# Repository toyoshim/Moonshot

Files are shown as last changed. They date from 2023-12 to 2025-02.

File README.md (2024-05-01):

# Moonshot
USB to Legacy Joystick port converter.

# License
The 3-Clause BSD License is applied for project specific all resources under
docs, firmware, and tools directories. See LICENSE.bsd3 for details.

Creative Commons NonCommercial license is applied for project specific all
resources under KiCAD directory. See LICENSE.cc_by_nc for details.

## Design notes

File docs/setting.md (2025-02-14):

---
layout: default
title: サポートページ
permalink: /setting
---
# レイアウト設定
---
左側のUSBポートをUSB A to AのケーブルでPCに接続してください。
標準規格外のケーブルですが、Amazonで「USB A to A」などで検索すると見つかります。
この際、ジョイスティック端子には接続せずに、単体でPCと接続してください。
LEDが高速に点滅していたら設定モードでの起動に成功しています。
OSからはシリアルポートとして認識され、ブラウザからは"Moonshot"の名前でアクセスできるようになります。

デバイスを繋げたら「接続」ボタンを押し、デバイス選択ダイアログからMoonshotを選んで「接続」を押します。
デバイスがない場合は「デモ」ボタンから擬似的にツールを体験できます。

（注）ウェブ上での設定はChromiumベースのブラウザ専用です。Google ChromeやMicrosoft Edgeなどでご利用ください。

<button id="connect">接続</button>
<button id="demo">デモ</button>
<pre id="console" align="center"></pre>

<style type="text/css">
@font-face {
  font-family: 'Elisa8';
  src: url('JF-Dot-Elisa8.ttf') format('truetype');
}

pre.console-line {
  margin: 0;
  padding: 0;
  border: 0;
  font-size: 12px;
  font-family: 'Elisa8', monospace;
  line-height: 1;
  box-shadow: none;
  text-shadow: 0 0 1rem #0f0, 0 0 1rem #00f;
}
</style>
<script type="text/javascript" src="./console.js"></script>
<script type="text/javascript" src="./io.js"></script>
<script type="text/javascript">
  var Module = {
    console: new Console(96, 32, document.getElementById('console')),
    io: new IO(this.console),
    print: (text) => console.log(text),
    printErr: (text) => console.error(text),
    ms_comm: async (len, cmd_ptr, res_ptr) => {
      if (!this.Module.io.connected()) {
        return 128;
      }
      this.Module.HEAPU8[res_ptr + 0] = 0xff;
      this.Module.HEAPU8[res_ptr + 1] = 0x00;
      this.Module.HEAPU8[res_ptr + 2] = 0x00;
      this.Module.HEAPU8[res_ptr + 3] = 0x00;
      this.Module.HEAPU8[res_ptr + 4] = 0x00;
      this.Module.HEAPU8[res_ptr + 5] = 0xff;
      let error = 0;
      for (let i = 0; i < len; ++i) {
        let result = await this.Module.io.comm(this.Module.HEAPU8[cmd_ptr + i]);
        if (!result) {
          error = 129;
          break;
        }
        this.Module.HEAPU8[res_ptr + 4 * i + 6] = result[0];
        this.Module.HEAPU8[res_ptr + 4 * i + 7] = result[1];
        this.Module.HEAPU8[res_ptr + 4 * i + 8] = result[2];
        this.Module.HEAPU8[res_ptr + 4 * i + 9] = result[3];
      }
      return new Promise((resolve, reject) => {
        setTimeout(e => {
          resolve(error);
        }, 1);
      });
    },
    bitsns: bitsns => {
      return this.Module.io.iocs_bitsns(bitsns);
    },
    preRun: () => {
      this.printChar = (stream, curr) => {
        this.Module.console.print(stream, String.fromCharCode(curr));
      };
      this.Module.console.print(0, "A>MSCONF.X\n");
    },
    postRun: () => {
      setTimeout(e => {
        this.Module.console.print(0, "A>\n");
      }, 1);
    },
  };
  document.getElementById('connect').addEventListener('click', async e => {
    await Module.io.connect();
    if (Module.io.connected()) {
      Module._main();
    }
  });
  document.getElementById('demo').addEventListener('click', async e => {
    Module.io.demo = true;
    if (Module.io.connected()) {
      Module._main();
    }
  });
</script>
<script async type="text/javascript" src="msconf.js"></script>
アナログ設定の+/-で出力値の極性を変更でき、上下左右の反転などの効果があります。

標準ではサイバースティックのボタン名が最上段に表示されていますが、
「L」ボタンを押すことでカプコンアダプターやメガドライブ6ボタン、
標準2ボタンの表記になります。

レイアウト変更後は「S」ボタンで設定後のレイアウトをMoonshotに保存します。

このページと同様の設定がX68k上から行えます。
実機上では押したボタンや設定した出力の状態がリアルタイムで表示されるため、確認が簡単にできます。

（注）接続やデモは複数回押すとうまく動作しないため、エラーが出たらページをリロードしてお試しください。

# X680x0版設定ツール
---
[X68kから利用するツール msconf.x](https://github.com/toyoshim/Moonshot/tree/main/tools)が用意されています。

各種エミュレータやX68000ZからじょいぽーとＵ君ごしに利用している場合、
U君をNOTIFYモードにした上で Moonshotを「低速通信モード」に、
それ以外では「サイバースティックモード」にした後にmsconf.xを起動して設定します。

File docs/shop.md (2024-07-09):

---
layout: default
title: 販売
permalink: /shop
---
# 販売
---
## 取り扱い店舗

- 家電のケンちゃん [Mellow PCB MP14-Moonshot (USB to ATARI converter)](https://www.kadenken.com/view/item/000000001709)

販売開始しました。随時出荷しておりますので、品切れの際は再入荷のお知らせを使ってお待ち下さい。

## ケース

- TNB製作所`s SHOP [X68000 シリーズ用 USB to ATARI converter MP14 Moonshot用 ケース](https://tnb216.booth.pm/items/5867125)

[くにちこ](https://twitter.com/kunichiko)さん設計のケースを[たんぼ（TNB製作所）](https://twitter.com/h_koma2)さんが製造・販売してくれています。LEDやボタンの扱いにも配慮されており、大変良く出来たケースになっています。

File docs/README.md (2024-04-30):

---
layout: default
title: サポートページ
permalink: /
---
{: align="center"}
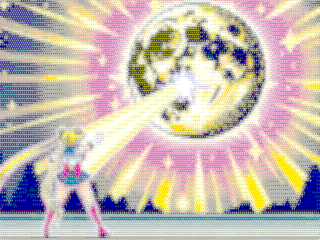
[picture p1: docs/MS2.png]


[暫定版PDF簡易マニュアル](papers/draft.pdf)

# 取り扱い説明書
---
## 概要
USBのゲームコントローラをアタリ系ジョイスティックポートに変換する装置です。

Xbox系やPS系を始めとする多くのUSBゲームコントローラに対応し（*1）、アナログ入力含めて柔軟に再割り当てを行い、X68kやMSXなどで利用しているアタリ仕様端子に変換します。

基本的なアタリ仕様に加えて、CPSFの6ボタンや、サイバースティック、チェルノブアダプタを使ったメガドライブ3B/6B仕様をエミュレートできます。

(*1) USBゲームコントローラの仕様は多岐に渡り、仕様をまもっていないもの、固有のコマンドを送らないと動作しないようプロテクトが掛かっているものなどがあるため、全てのコントローラでの動作を保証するものではありません。

## 各部の説明
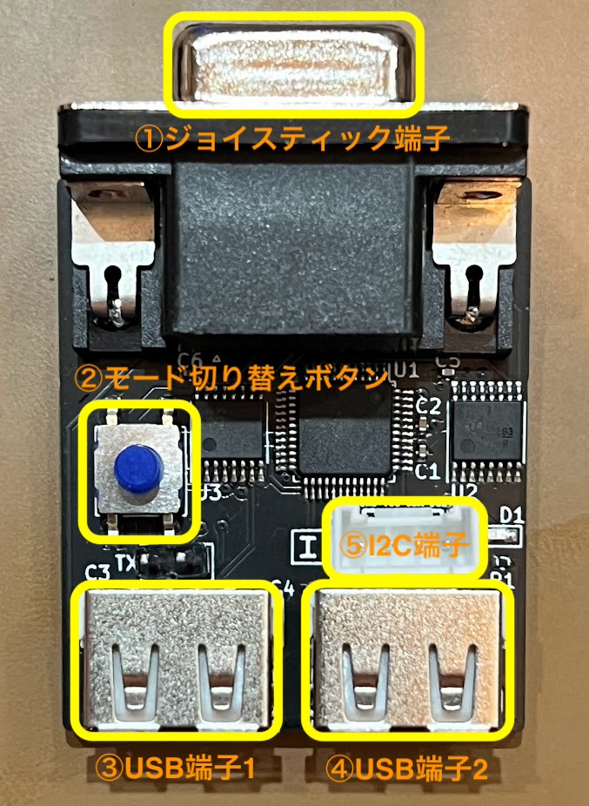
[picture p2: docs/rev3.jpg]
Rev3

### ①ジョイスティック端子
X68kやMSXなどと接続します。ここから電源も供給されます。

### ②モード切り替えボタン
各動作モードの切り替えを行います。選択中のモードは電源を切っても記録されます。

ファームウェア1.01.0以降ではマイナーモードに入る際に1秒以上押し続ける必要があります。

### ③USB端子1
ゲームコントローラを接続します。

公式にサポートしているコントローラについては姉妹品IONA-USサポートページ内にある
[ファームウェアの互換性](https://toyoshim.github.io/iona-us/firmware)をご確認ください。
これ以外でも多くのコントローラが動作します。

PCと接続する際にも利用しますが、その際①は必ず切り離してください。

### ④USB端子2

未使用、将来の拡張用です。いずれ2P対応やコントローラ以外のUSBデバイスをサポートする可能性があります。

### ⑤I2C端子

I2C規格に則った通信ができます。主に開発者向けの機能です。
簡単な技術情報は[GitHub内のWiki](https://github.com/toyoshim/Moonshot/wiki/I2C-Support)に書かれています。興味ある方はお気軽にお声がけください。

現在はデバイスとして動作しますが、将来的にはホストとしてI2Cデバイスを制御する機能を追加する予定です。

## 動作モード詳細

| LEDの状態 | 動作モード | 概要 |
|-|-|-|
| 点灯 | 通常モード | 標準的な2ボタンと上下・左右同時押しを利用したSTART/SELECTボタンに対応しています。CPSF等の変換器が用いていた6ボタン拡張にも対応しています。 |
| 高速点滅 | サイバースティックモード | サイバースティック互換のアナログ対応モードです。4軸全て動作します。動作確認状況については[こちら](https://github.com/toyoshim/Moonshot/wiki/%E4%BA%92%E6%8F%9B%E6%80%A7%E7%A2%BA%E8%AA%8D%E7%8A%B6%E6%B3%81)をご確認ください。またmsconf.xなどのツールはこのモードでサイバースティックのプロトコルを拡張して動作します。|
| 低速点滅 | 低速通信モード (マイナーモード) | じょいぽーとU君に対応したエミュレータやX68000Zで利用するためのモードです。|
| 2回点滅 | メガドライブモード | チェルノブコンバーターを用いてメガドライブ用のコントローラをアタリ端子に変換した時の動作をエミュレートします。6ボタンプロトコルにも対応しています。|
| 3回点滅 | リブルラブルモード | リブルラブルのツインスティックコントローラをエミュレートします。右スティックはアナログのThとX2がアサインされます。ファームウェア1.01.0以降で追加されています。|

## レイアウト変更
[X68kから利用するツール](https://github.com/toyoshim/Moonshot/tree/main/tools)と
同ツールをウェブから利用できるようにした[ページ](setting)があります。

{: align="center"}
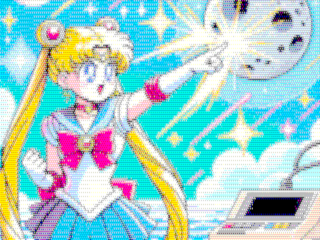
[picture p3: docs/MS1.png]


# 将来できるかもしれないこと
---
- 専用ドライバを使い右側のポートを2P用に利用
  + IOCSをフックする予定なので、直接I/Oを叩いたゲーム等には対応できません
- 同様にしてキーボード、マウスに対応
- USBハブを経由した接続に対応
- I2Cを用いた機器の制御
- [x68kzremotedrv](https://github.com/yunkya2/x68kzremotedrv)のマウント

# Special Thanks
---
βテストで沢山の方にご協力頂きました。お名前の掲載を許可頂いた方のみ掲載させて頂きます。
協力していただいたすべての方に感謝します。
また、購入して頂いた方も、ぜひフィードバックで改善にご協力お願いします。
特殊入力に対応したゲームを作りたい方、X68k以外のプラットフォームでのツールを作りたい方、I2Cモードで使ってみたい方なども遠慮なくご相談ください。
アップデート可能なデバイスですので、色々と楽しくしていけたらと思います。

- [くにちこ](https://twitter.com/kunichiko)
- [たんぼ（TNB製作所）](https://twitter.com/h_koma2)
- 前廣和豊
- [みゆ🌹ฅ^•ω•^ฅ (miyu rose) ](https://twitter.com/arith_rose)

（継承略、五十音順）

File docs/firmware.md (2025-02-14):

---
layout: default
title: ファームウェア更新
permalink: /firmware
---
# ファームウェアアップデート
---
## 事前準備
### USB Type A to Type Aのケーブル
Moonshot上の青いボタンを押しながら、左側のUSBポートをUSB A to AのケーブルでPCに接続してください。
標準規格外のケーブルですが、Amazonで「USB A to A」などで検索すると見つかります。
この際、ジョイスティック端子には接続せずに、単体でPCと接続してください。

ファームウェア更新モードで接続するとLEDは消灯します。

### WinUSBのドライバの設定（Windowsのみ）
Windowsに限ってドライバが必要となります。Windows 10以降では標準で搭載されています。
自動ではインストールされないので、手動で`ユニバーサル シリアル バス デバイス`から`WinUsb デバイス`を選択してインストールする必要があります。
詳細は[Microsoft公式情報](https://learn.microsoft.com/ja-jp/windows-hardware/drivers/usbcon/winusb-installation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)をご参照ください。
参考動画も[こちら](https://www.youtube.com/watch?v=5yzpc2vI_94)にあります。

USBホストとの相性問題があるようで、ドライバがうまくスタートできない事があります。
使用しているチップのファームウェア更新モードにある問題なので根本的な修正ができないのですが、リトライする、他のUSBポートを試してみる、USBハブ越しに接続する、他のUSB機器（特に近いポートに刺さっているもの）を外して試す、などが有効なようです。Windows以外のOSでは相性問題は発生しません。

また[Zadig](https://zadig.akeo.ie/)というソフトウェアを使ってWinUSBのドライバを管理する方法もあります。
日本語の解説ページも探すとあるかと思いますので、必要に応じてご利用ください。
インストール操作が簡単なのと、インストールするドライバが選択できるので、互換性問題も回避できる可能性があります。

### USB OTGの設定（Androidのみ）
Windowsで互換性問題が発生した方や、PCはないけどスマホならある、という方はAndroid Chromeが利用できます。
利用に際してはAndroidがOTG（USB Hostモード）をサポートしている必要があります。
また、端子がUSB Cの場合でもC to Aで接続しただけではデバイスモードになってしまいます。
まずはOTG対応のType Aのメスコネクタに変換するアダプタを接続し、そこからA to Aで接続してください。

### udevの設定（Linuxのみ）
多くのLinux環境では接続したUSBのアクセス権限を適切に制御するためにudevと呼ばれるシステムが利用されています。
`/etc/udev/` ディレクトリが存在している場合は、[こちら](https://github.com/toyoshim/iona-us/blob/main/docs/linux/99-ch559-bootloader.rules)のファイルを`/etc/udev/rules.d/99-ch559-bootloader.rules`として保存してからデバイスを再接続して下さい。

あるいは同ファイル名で以下の内容を保存して下さい。
```
ATTRS{idVendor}=="4348", ATTRS{idProduct}=="55e0", MODE="0666"
```

## アップデート
ここから先はChromiumベースのブラウザが必要です。
Google ChromeやMicrosoft Edgeなどをご利用ください。

書き込みたいバージョンをメニューから選び「書き込み」ボタンを押すと、デバイス選択ダイアログが表示されます。
デバイスが正しく認識されていれば「WinChipHead製の不明なデバイス」に準じた名前がリストされますので、その名前を選択した上で「接続」ボタンを押すことで、アップデートが開始します。

チップが一枚だけ載った初期の物がプロトタイプ、チップが3枚載り裏にMoonshotと記載されているのが製品候補です。

<script src="https://toyoshim.github.io/CH559Flasher.js/CH559Flasher.js"></script>
<script>
async function flash() {
  const firmwares = [
    'firmwares/ms_v1_00_0.bin',
    'firmwares/ms2_v1_00_0.bin',
    'firmwares/ms2_v1_00_0.bin',
    'firmwares/ms2_v1_01_0.bin',
    'firmwares/ms2_v1_02_0.bin',
  ];
  const progressWrite = document.getElementById('progress_write');
  const progressVerify = document.getElementById('progress_verify');
  const error = document.getElementById('error');
  progressWrite.value = 0;
  progressVerify.value = 0;
  error.innerText = '';

  const flasher = new CH559Flasher();
  await flasher.connect();
  await flasher.erase();
  const url = firmwares[document.getElementById('version').selectedIndex];
  const response = await fetch(url);
  if (response.ok) {
    const bin = await response.arrayBuffer();
    await flasher.write(bin, rate => progressWrite.value = rate);
    await flasher.verify(bin, rate => progressVerify.value = rate);
    error.innerText = flasher.error ? flasher.error : '成功';
  } else {
    error.innerText = 'ファームウェアが見つかりません';
  }
}
</script>

<select id="version">
<option>プロトタイプ用 Ver 1.00.0</option>
<option>製品候補用 Ver 1.00.0</option>
<option>製品用 Ver 1.00.0</option>
<option>製品用 Ver 1.01.0</option>
<option selected>製品用 Ver 1.02.0</option>
</select>
<button onclick="flash();">書き込み</button>

| | |
|-|-|
|書き込み|0% <progress id="progress_write" max=1 value=0></progress> 100%|
|検証|0% <progress id="progress_verify" max=1 value=0></progress> 100%|

結果
<pre id="error"></pre>

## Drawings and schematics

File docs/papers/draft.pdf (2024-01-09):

# MP14-Moonshot

## Rev 4 PCB, Designed By Mellow PCB

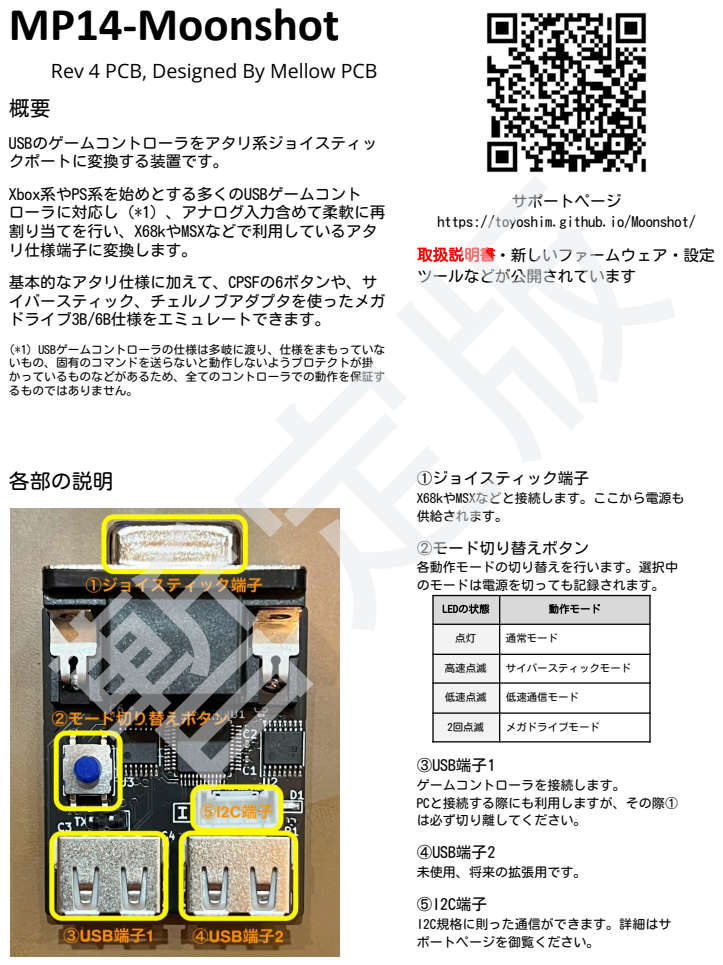
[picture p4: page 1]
USBのゲームコントローラをアタリ系ジョイスティッ クポートに変換する装置です。; Xbox系やPS系を始めとする多くのUSBゲームコント ローラに対応し（*1）、アナログ入力含めて柔軟に再 割り当てを行い、X68kやMSXなどで利用しているアタ リ仕様端子に変換します。; 基本的なアタリ仕様に加えて、CPSFの6ボタンや、サ イバースティック、チェルノブアダプタを使ったメガ ドライブ3B/6B仕様をエミュレートできます。; (*1) USBゲームコントローラの仕様は多岐に渡り、仕様をまもっていな いもの、固有のコマンドを送らないと動作しないようプロテクトが掛 かっているものなどがあるため、全てのコントローラでの動作を保証す るものではありません。; サポートページ; 各部の説明; ①ジョイスティック端子; X68kやMSXなどと接続します。ここから電源も 供給されます。; ②モード切り替えボタン; 各動作モードの切り替えを行います。選択中 のモードは電源を切っても記録されます。; ③USB端子1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

https://toyoshim.github.io/Moonshot/

取扱説明書・新しいファームウェア・設定
ツールなどが公開されています

LEDの状態 | 動作モード

点灯 | 通常モード

高速点滅 | サイバースティックモード

低速点滅 | 低速通信モード

2回点滅 | メガドライブモード

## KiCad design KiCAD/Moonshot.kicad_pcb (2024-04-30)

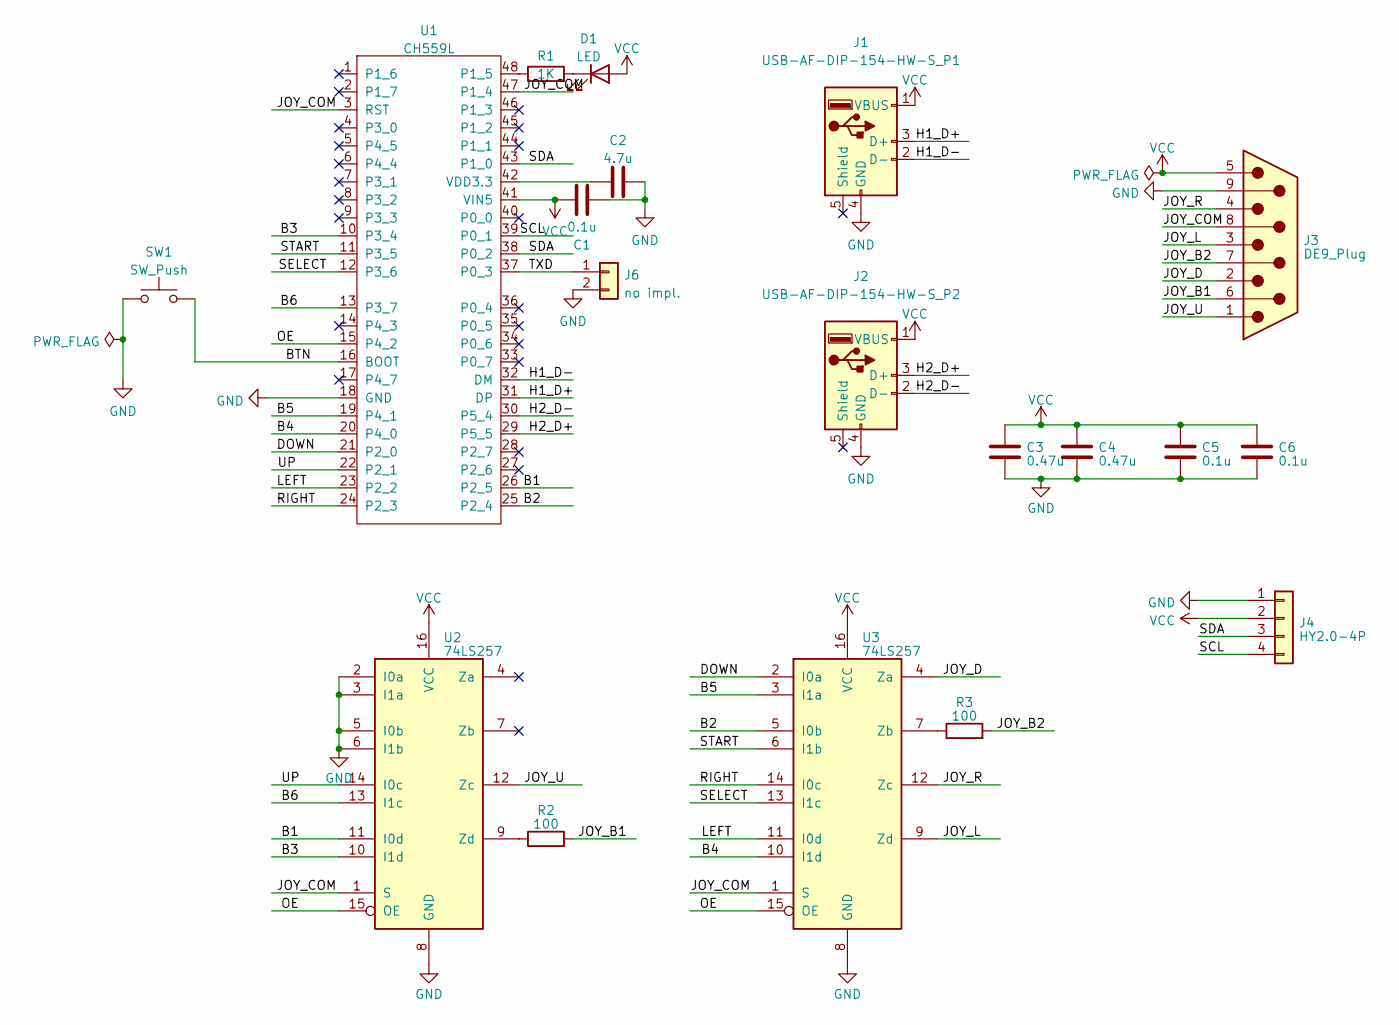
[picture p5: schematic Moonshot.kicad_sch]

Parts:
C1, C5, C6: 0.1u; C_0402_1005Metric
C2: 4.7u; C_0402_1005Metric
C3, C4: 0.47u; C_0402_1005Metric
D1: LED; LED_0603_1608Metric_Pad1.05x0.95mm_HandSolder; LCSC C965807
J1: USB-AF-DIP-154-HW-S_P1; USB-A-TH_JTJ-USB-A-F-10.0-010; LCSC C42576
J2: USB-AF-DIP-154-HW-S_P2; USB-A-TH_JTJ-USB-A-F-10.0-010; LCSC C42576
J3: DE9_Plug; DSUB-9_Female_TE_2301844_1; LCSC C3135162
J4: HY2.0-4P; CONN-TH_4P-P2.00_HX20020-4A_2; LCSC C7429580
J6: no impl.; PinHeader_2x01_P2.54mm_Vertical
R1: 1K; R_0402_1005Metric
R2, R3: 100; R_0402_1005Metric
SW1: SW_Push; TS-1159B; LCSC C381055
U1: CH559L; LQFP-48_7x7mm_P0.5mm; LCSC C150548
U2, U3: 74LS257; TSSOP-16_4.4x5mm_P0.65mm; LCSC C2868824

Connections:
/B1: U1.26 (P2_5), U2.11 (I0d)
/B2: U1.25 (P2_4), U3.5 (I0b)
/B3: U1.10 (P3_4), U2.10 (I1d)
/B4: U1.20 (P4_0), U3.10 (I1d)
/B5: U1.19 (P4_1), U3.3 (I1a)
/B6: U1.13 (P3_7), U2.13 (I1c)
/BTN: SW1.2, U1.16 (BOOT)
/DOWN: U1.21 (P2_0), U3.2 (I0a)
/H1_D+: J1.3 (D+), U1.31 (DP)
/H1_D-: J1.2 (D-), U1.32 (DM)
/H2_D+: J2.3 (D+), U1.29 (P5_5)
/H2_D-: J2.2 (D-), U1.30 (P5_4)
/JOY_B1: J3.6, R2.2
/JOY_B2: J3.7, R3.2
/JOY_COM: J3.8, U1.3 (RST), U1.47 (P1_4), U2.1 (S), U3.1 (S)
/JOY_D: J3.2, U3.4 (Za)
/JOY_L: J3.3, U3.9 (Zd)
/JOY_R: J3.4, U3.12 (Zc)
/JOY_U: J3.1, U2.12 (Zc)
/LEFT: U1.23 (P2_2), U3.11 (I0d)
/OE: U1.15 (P4_2), U2.15 (OE), U3.15 (OE)
/RIGHT: U1.24 (P2_3), U3.14 (I0c)
/SCL: J4.4, U1.39 (P0_1)
/SDA: J4.3, U1.38 (P0_2), U1.43 (P1_0)
/SELECT: U1.12 (P3_6), U3.13 (I1c)
/START: U1.11 (P3_5), U3.6 (I1b)
/TXD: J6.1, U1.37 (P0_3)
/UP: U1.22 (P2_1), U2.14 (I0c)
GND: C1.2, C2.2, C3.2, C4.2, C5.2, C6.2, J1.4 (GND), J2.4 (GND), J3.9, J4.1, J6.2, SW1.1, U1.18 (GND), U2.2 (I0a), U2.3 (I1a), U2.5 (I0b), U2.6 (I1b), U2.8 (GND), U3.8 (GND)
unnamed: D1.1 (K), R1.2
unnamed: R1.1, U1.48 (P1_5)
unnamed: C2.1, U1.42 (VDD3.3)
unnamed: R2.1, U2.9 (Zd)
unnamed: R3.1, U3.7 (Zb)
VCC: C1.1, C3.1, C4.1, C5.1, C6.1, D1.2 (A), J1.1 (VBUS), J2.1 (VBUS), J3.5, J4.2, U1.41 (VIN5), U2.16 (VCC), U3.16 (VCC)

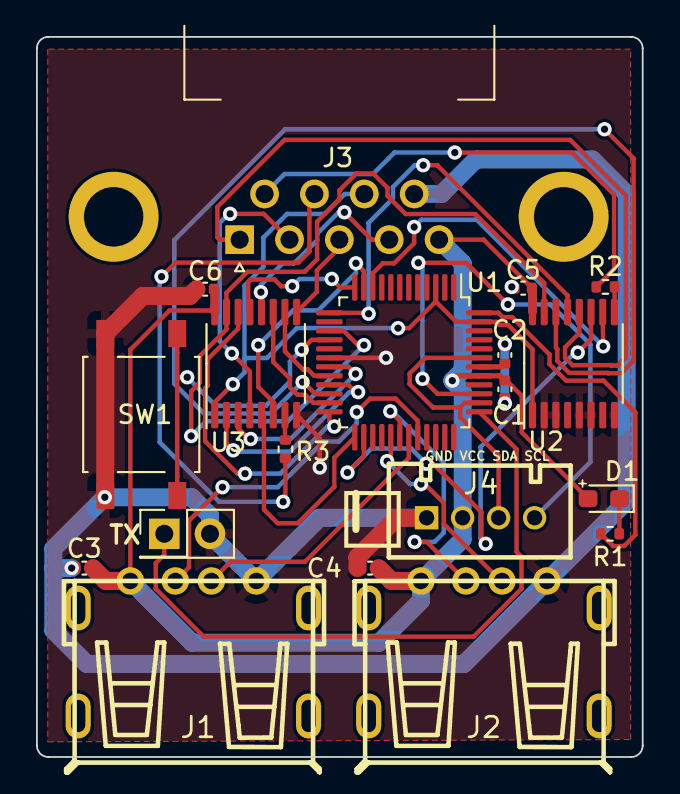
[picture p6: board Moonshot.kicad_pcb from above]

Board: 2 copper layers, 33.7 x 40.0 mm, 19 parts (0 on the bottom side), 35 nets.

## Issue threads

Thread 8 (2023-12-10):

マウスやトラックボールの入力値補正

toyoshim, 2023-12-10:
イーグレットツーミニ用の拡張コントローラも含め、マウスやトラックボールだと入力がデルタ値になって、サイバースティックのプロトコルで期待してる値レンジとマッチしない。なんらかの倍率設定が必要かも。

toyoshim, 2023-12-10:
ハンドルでも調整欲しい。

toyoshim, 2025-06-22:
メガドラのアナログタイトル、たぶん感度を倍くらいに上げたほうが操作感が良いと思われる
（カブトガニで調整されてるとすると、入力がピーキーになりがちなので感度を下げてそう）

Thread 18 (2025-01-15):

メガドライブで使った時にアフターバーナーのアナログモードでスロットが反応しない？

toyoshim, 2025-01-15:
前は動いてたと思うけど、動かない方向があったので要再確認

toyoshim, 2025-02-09:
問題なし。
メガドライブでは、スロットルとスティック、ともにXとYが入れ替わっているので
Analog 1 (LX) => Y（実際にはX）
Analog 2 (LY) => X（実際にはY）
Analog 3 (RX) => Th（実際には未使用）
Analog 4 (RY) => X2（スロットル）
の設定でいける。

Closed 2025-02-09.

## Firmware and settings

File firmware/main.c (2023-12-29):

// Copyright 2023 Takashi Toyoshima <toyoshim@gmail.com>. All rights reserved.
// Use of this source code is governed by a BSD-style license that can be found
// in the LICENSE file.

#include "ch559.h"
#include "gpio.h"
#include "led.h"
#include "serial.h"
#include "timer3.h"
#include "usb/cdc_device.h"
#include "usb/hid/hid.h"
#include "usb/usb_device.h"
#include "usb/usb_host.h"

#include "atari.h"
#include "command.h"
#include "controller.h"
#include "settings.h"
#include "version.h"

// #define _DBG

static const char kString01Manufacturer[] = "Mellow PCB - mellow.twintail.org";
static const char kString02Product[] = "Moonshot";
static const char kString03SerialNumber[] = VERSION_STRING;

static uint8_t get_string_length(uint8_t no) {
  switch (no) {
    case 1:
      return sizeof(kString01Manufacturer) - 1;
    case 2:
      return sizeof(kString02Product) - 1;
    case 3:
      return sizeof(kString03SerialNumber) - 1;
  }
  return 0;
}

static const char* get_string(uint8_t no) {
  switch (no) {
    case 1:
      return kString01Manufacturer;
    case 2:
      return kString02Product;
    case 3:
      return kString03SerialNumber;
  }
  return 0;
}

void recv(const uint8_t* buffer, uint8_t len) {
  uint8_t response[4];
  for (uint8_t i = 0; i < len; ++i) {
    command_execute(buffer[i], response);
    cdc_device_send(response, 4);
  }
}

static void detected(void) {
  led_oneshot(L_PULSE_ONCE);
}

static uint8_t get_flags(void) {
  return USE_HUB0 | USE_HUB1;
}

void main(void) {
  bool device_mode = false;

  initialize();

  timer3_tick_init();

  struct cdc_device device;
  device.id_vendor = 0x0483;
  device.id_product = 0x16c0;
  device.bcd_device = 0x0100;
  device.get_string_length = get_string_length;
  device.get_string = get_string;
  device.recv = recv;
  cdc_device_init(&device);

  led_init(1, 5, LOW);
  led_mode(L_ON);

  settings_init();

  atari_init();

  Serial.print("\nMP14-Moonshot ver " VERSION_STRING " - ");

  while (timer3_tick_raw() < 0x3000) {
    uint8_t state = usb_device_state();
    led_poll();
    if (state != UD_STATE_IDLE) {
      device_mode = true;
      break;
    }
  }
#ifndef _DBG
  if (device_mode) {
    Serial.println("CDC mode");
    led_mode(L_FASTER_BLINK);
    for (;;) {
      led_poll();
    }
  }
#endif
  Serial.println("HOST mode");

  struct hid hid;
  hid.report = controller_update;
  hid.detected = detected;
  hid.get_flags = get_flags;
  hid_init(&hid);
  usb_host_reset();

  for (;;) {
    hid_poll();
    led_poll();
    atari_poll();

#ifdef _DBG
    {
      static bool init = false;
      if (!init) {
        Serial.println(
            "\r\nUp Dw Lf Rt B1 B2 B3 B4 L1 R1 L2 R2 Sl St L3 R3 A0   A1   A2 "
            "  A3   A4   A5");
        init = true;
      }
      uint16_t v = controller_raw_digital(1);
      for (uint16_t b = 0x8000; b != 0; b >>= 1) {
        Serial.printf("%d  ", (v & b) ? 1 : 0);
      }
      for (uint8_t i = 0; i < 6; ++i) {
        uint16_t v = controller_raw_analog(1, i);
        Serial.printf("%x%x,", (v >> 8) & 0xff, v & 0xff);
      }
      Serial.printf("\r");
    }
#endif
  }
}

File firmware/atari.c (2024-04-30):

// Copyright 2023 Takashi Toyoshima <toyoshim@gmail.com>. All rights reserved.
// Use of this source code is governed by a BSD-style license that can be found
// in the LICENSE file.

#include "atari.h"

#include <stdbool.h>
#include <stdint.h>

#include "chlib/src/io.h"
#include "chlib/src/timer3.h"
#include "gpio.h"
#include "grove.h"
#include "io.h"
#include "led.h"
#include "serial.h"
#include "timer3.h"
#include "uart1.h"

#include "command.h"
#include "controller.h"
#include "settings.h"

// #define PROTO1

enum {
  MODE_NORMAL = 0,  // Normal 2 buttons, or Capcom 6 buttons mode
  MODE_CYBER = 1,   // Cyber Stick mode
  MODE_SAFE = 2,    // Safe mode
  MODE_MD = 3,      // Mega Drive 3B / 6B
  MODE_LR = 4,      // Libble Rabble
#ifdef PROTO1
  MODE_LAST = MODE_SAFE,
#else
  MODE_LAST = MODE_LR,
#endif
};

#define MD_STATE_TIMEOUT 2048
#define MD_STATE_SHORT_TIMEOUT 64

#define CYBER_TIMEOUT 150
#define CYBER_MINIMUM 10
#define CYBER_SAFE_TIMEOUT 0x7fff
#define CYBER_SAFE_MINIMUM 0x7000

static volatile uint8_t out[6] = {0xff, 0xff, 0xff, 0xff, 0xff, 0xff};
static uint16_t frame_timer = 0;
static bool button_pressed = false;
static volatile uint8_t mode = MODE_NORMAL;
static volatile uint8_t nop = 0;  // used to avoid compiler optimization

static volatile uint16_t cyber_timeout = CYBER_TIMEOUT;
static volatile uint16_t cyber_minimum = CYBER_MINIMUM;
static volatile bool cyber_skip = false;

#ifdef PROTO1

#define GPIO_COM P2_6

#define SET_LOW_CYCLE_SIGNALS(v) P2 = 0x20 | (v)
#define SET_HIGH_CYCLE_SIGNALS(v) P2 = 0x30 | (v)
#define SET_READY() P2_5 = 0
#define RESET_READY() P2_5 = 1

#else

#define GPIO_COM P1_4

#define SET_LOW_CYCLE_SIGNALS(v)       \
  {                                    \
    uint8_t adjusted_value = swaph[v]; \
    P4_OUT = adjusted_value;           \
    P3 = 0x20 | adjusted_value;        \
    P2 = 0x10 | swapl[v];              \
  }
#define SET_HIGH_CYCLE_SIGNALS(v)      \
  {                                    \
    uint8_t adjusted_value = swaph[v]; \
    P4_OUT = adjusted_value;           \
    P3 = 0x30 | adjusted_value;        \
    P2 = 0x30 | swapl[v];              \
  }
#define SET_READY() \
  {                 \
    P2_4 = 0;       \
    P3_5 = 0;       \
  }

#define RESET_READY() \
  {                   \
    P2_4 = 1;         \
    P3_5 = 1;         \
  }

static uint8_t swaph[16] = {
    0x00,  // xxxx0000 => 00xxxx00
    0x80,  // xxxx0001 => 10xxxx00
    0x02,  // xxxx0010 => 00xxxx10
    0x82,  // xxxx0011 => 10xxxx10
    0x01,  // xxxx0100 => 00xxxx01
    0x81,  // xxxx0101 => 10xxxx01
    0x03,  // xxxx0110 => 00xxxx11
    0x83,  // xxxx0111 => 10xxxx11
    0x40,  // xxxx1000 => 01xxxx00
    0xc0,  // xxxx1001 => 11xxxx00
    0x42,  // xxxx1010 => 01xxxx10
    0xc2,  // xxxx1011 => 11xxxx10
    0x41,  // xxxx1100 => 01xxxx01
    0xc1,  // xxxx1101 => 11xxxx01
    0x43,  // xxxx1110 => 01xxxx11
    0xc3,  // xxxx1111 => 11xxxx11
};
static uint8_t swapl[16] = {
    0x00,  // xxxx0000 => xxxx0000
    0x02,  // xxxx0001 => xxxx0010
    0x01,  // xxxx0010 => xxxx0001
    0x03,  // xxxx0011 => xxxx0011
    0x04,  // xxxx0100 => xxxx0100
    0x06,  // xxxx0101 => xxxx0110
    0x05,  // xxxx0110 => xxxx0101
    0x07,  // xxxx0111 => xxxx0111
    0x08,  // xxxx1000 => xxxx1000
    0x0a,  // xxxx1001 => xxxx1010
    0x09,  // xxxx1010 => xxxx1001
    0x0b,  // xxxx1011 => xxxx1011
    0x0c,  // xxxx1100 => xxxx1100
    0x0e,  // xxxx1101 => xxxx1110
    0x0d,  // xxxx1110 => xxxx1101
    0x0f,  // xxxx1111 => xxxx1111
};
#endif

static void wait(uint16_t count) {
  for (uint16_t i = 0; i < count; ++i) {
    ++nop;
    if (GPIO_COM) {
      ++nop;
    }
  }
}

static bool wait_posedge(uint16_t timeout) {
  uint16_t count;
  for (count = 0; count != timeout; ++count) {
    ++nop;
    if (GPIO_COM) {
      break;
    }
  }
  return count != timeout;
}

static bool wait_negedge(uint16_t timeout) {
  uint16_t count;
  for (count = 0; count != timeout; ++count) {
    ++nop;
    if (!GPIO_COM) {
      break;
    }
  }
  return count != timeout;
}

static void gpio_int(void) {
  if (mode == MODE_MD) {
    if (!GPIO_COM) {
      return;
    }
    // The fist posedge.
    if (!wait_negedge(MD_STATE_TIMEOUT)) {
      goto MD_TIMEOUT;
    }
    if (!wait_posedge(MD_STATE_TIMEOUT)) {
      goto MD_TIMEOUT;
    }
    // The second posedge. Let's prepare for the next special low cycle there
    // 3:0 goes low.
    P2 = out[0] & 0xf0;
    if (!wait_negedge(MD_STATE_TIMEOUT)) {
      goto MD_TIMEOUT;
    }
    // Prepare for the next high cycle for X, Y, Z, and Mode.
    P3 = out[2];
    P4_OUT = out[2];
    if (!wait_posedge(MD_STATE_TIMEOUT)) {
      goto MD_TIMEOUT;
    }
    // Prepare for the next low cycle, the final state.
    P2 = out[0];
    wait_negedge(MD_STATE_SHORT_TIMEOUT);

  MD_TIMEOUT:
    // Reset for the initial idle state anyway.
    P2 = out[0];
    P3 = out[1];
    P4_OUT = out[1];
    return;
  } else if (mode == MODE_CYBER || mode == MODE_SAFE) {
    // Do not check GPIO_COM state here because it might be already reset for
    // titles that do not give a enouugh wait, i.e. Star Cruiser just pulls it
    // only for 2us on 10MHz machine, or shorter on faster machines. The real
    // cyberstick can response only for 10MHz case actually.
    // On the other hand, false interrupt will be triggered immediately after
    // the extended protocol communication. So, if the cyber_skip is set, check
    // GPIO_COM only once here.
    if (GPIO_COM && cyber_skip) {
      cyber_skip = false;
      return;
    }
    // Also the real cyberstick seems to have 4 speed mode, 25us, 50us, 75us,
    // and 100us per half a cycle, and decides one of them based on the request
    // pulse width. Also, if the request has negated over 100us, it starts
    // sending back data in the fastest mode, 25us.
    // The following magic number cyber_minimum and cyber_timeout practically
    // works in the range, 25us through to 100us in the cyberstick mode.
    // For the safe mode, they are set to longer values so that it can work on
    // slow communication cases such as XM6 over U-kun, or X68000Z.
    uint16_t count;
    const uint16_t timeout = cyber_timeout;
    for (count = 0; count != timeout; ++count) {
      ++nop;
      if (GPIO_COM) {
        break;
      }
    }
    if (count == timeout) {
      // Disable the GPIO interrupt once to permit timer interrupts, etc for the
      // timeout case as there is a possible case the signal is stuck at low.
      IE_GPIO = 0;
      count = cyber_minimum;
    } else {
      if (count < cyber_minimum) {
        count = cyber_minimum;
      }
      for (uint8_t n = 0; n < 5; ++n) {
        wait(count);
      }
    }
    uint16_t command = 0;
    uint8_t n;
    for (n = 0; n < 6; ++n) {
      command <<= 1;
      command |= GPIO_COM ? 1 : 0;
      SET_LOW_CYCLE_SIGNALS(out[n] >> 4);
      wait(count);
      SET_READY();
      wait(count << 1);
      RESET_READY();
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

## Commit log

2023-10-22 rev2 pcb
    [JoynerX.dsn, JoynerX.kicad_pcb, JoynerX.kicad_sch]
2023-10-23 rename KiCAD files
    [Moonshot.dsn, Moonshot.kicad_pcb, Moonshot.kicad_sch]
2023-10-24 adjust data valid period as x68k seems failing to take data sometime
    [atari.c]
2023-10-27 stabilize cyberstick mode under unsupported situation (com is low)
    [atari.c]
2023-11-08 update README.md to clarify board types
2023-11-14 release high-priority interrupt only when the request reaches timeout
2023-11-25 v3 pcb
    [Moonshot.dsn, Moonshot.kicad_pcb, Moonshot.kicad_sch]
2023-11-25 i2c tentative support (unstable)
    [atari.c, grove.c, main.c]
2023-11-26 stabilize i2c support
    - chrlib roll and use exclusive_time feature
    - check if the interrupt was for the handler more precisely on each case
    - pull-up COM pin
    [atari.c, grove.c]
2023-12-01 use raw data for I2C
2023-12-02 move led ownership from settings to main
2023-12-02 bug fix: should accept 0xff while transaction
    [atari.c]
2023-12-02 fix for prot2 board
    [atari.c]
2023-12-10 0.99.9
    Modify cyberstick's timeout behavior.
    Moonshot just ignored if the request is stuck at low, but to follow
    the original cyberstick behavior, now it starts sending data
    at 25us per half a cycle speed. This is needed for some titles
    that detects cyberstick existence automatically. They hold the request
    low, and see if the response arrived within the next 100us.
    [atari.c, main.c]
2023-12-11 Implement Faces compatible I2C interface at address 0x08
2023-12-17 change the timeout value for the cdc/host mode detection
    It seems the counter is wrapped within 0x4000?
    Didn't check, but 0x4000 counter causes infinite loop
    [main.c]
2023-12-17 MSX0 I2C access support
    It needs to connect Moonshot to MSX0's internal I2C
    on starting the MSX emulator.
2023-12-18 bug fix: new_mode = mode + 1
    [atari.c]
2023-12-20 force usb bus reset to detect initially connected devices
    [main.c]
2023-12-28 Moonshot rev.4 board
    [Moonshot.dsn, Moonshot.kicad_pcb]
2023-12-29 fix the product # from 17 to 14
    [Moonshot.dsn, Moonshot.kicad_pcb]
2024-01-30 Rev.5 board
    [Moonshot.kicad_pcb, Moonshot.kicad_sch]
2024-04-30 PCB Rev.7
    [Moonshot.kicad_pcb, Moonshot.kicad_sch]
2024-04-30 extended protocol bug fix
    From the last fix for the 1.00.1, msconf.x doesn't work for
    false interrupt triggered for nested com signal edges.
    [atari.c]
2024-04-30 move safe mode to minor mode
    to enter the minor mode, users need to press the button for
    more than 1 second. otherwise, the mode is skipped.
    [atari.c]
2024-07-09 update shop.md to mention くにちこ&たんぼ's case
2025-02-12 update kicad proj
2025-02-22 msconf: bug fix on select/start button indicators
    Update to 1.02.1.
    In the previous version, output indicator mistakenly showed
    select and start button has been swapped.
2025-03-22 more bug fixes on mapper mode
    this is a kind of stable release for the early prototype
    of the Joypad Mapper for Z.
    [comm.h]
